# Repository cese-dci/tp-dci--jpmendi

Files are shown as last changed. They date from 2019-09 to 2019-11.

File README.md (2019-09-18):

# tp-dci--jpmendi
tp-dci--jpmendi created by GitHub Classroom

ARCHIVOS DEL TPFINAL DE DISEÑO DE PCB

El presente modulo es un control de motor de continua mediante de relay, con sensor de corriente,
para detener el mismo segun determinado torque, utilizando para ello un dip switch donde se pueden
activar distintas resistencias como referencias para que un PIC active o desactive los releay (uno para cada lado y 
un tercer relay que es para activar o desactivar la placa)

Posee dos entradas para los interruptores que estan fuera de la placa. y dos salidas a los motores

UN DETALLE: Requiere agregar ciertas pistas a la mascara antisoldante para para poder estañarlas luego de terminado el PCB

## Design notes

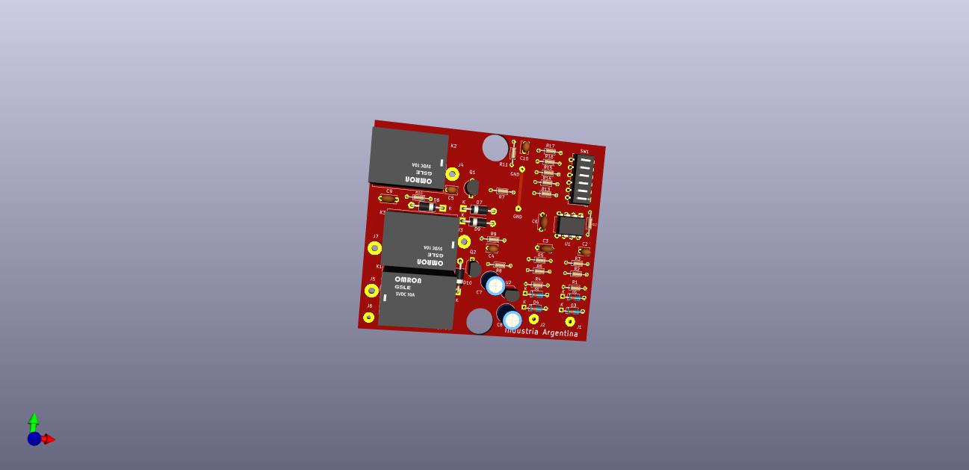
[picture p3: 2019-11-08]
TPFINAL2NOV19/DriverConSensor.jpg

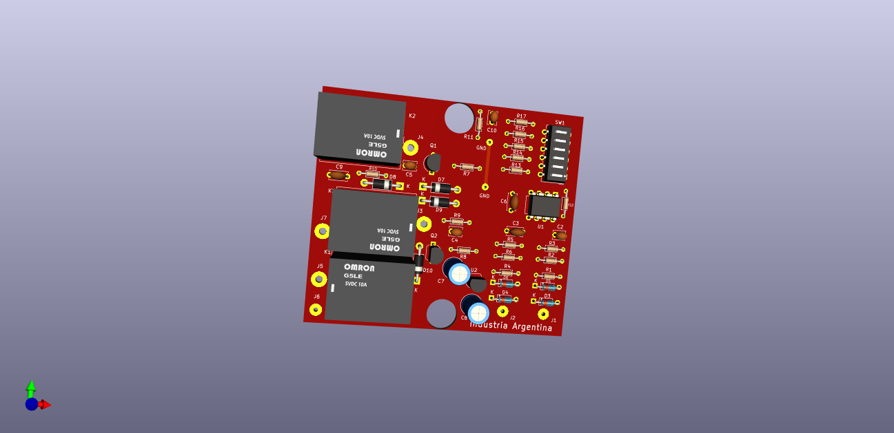
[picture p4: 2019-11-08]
TPFINAL2NOV19/DriverConSensor.png

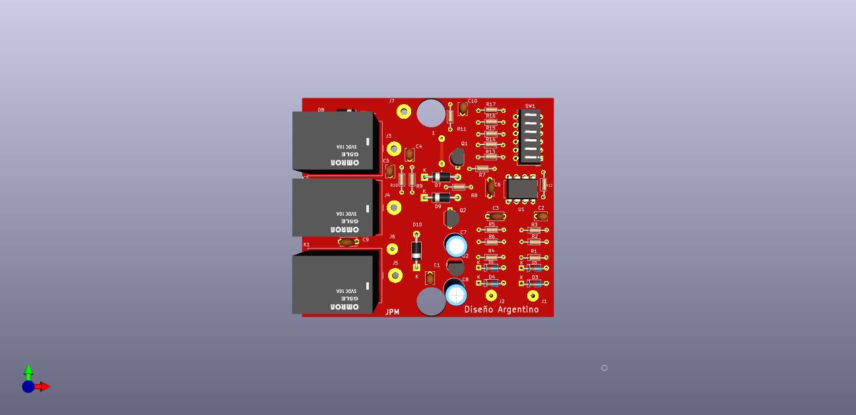
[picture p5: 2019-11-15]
TPFINAL2NOV19/Shapes3D/DriverConSensor.jpg

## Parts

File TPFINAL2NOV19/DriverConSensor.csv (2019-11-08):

Id | Designator | Package | Quantity | Designation | Supplier and ref
1 | K3,K2 | Relay_SPDT_Omron-G5LE-1 | 2 | FRS10CS10-12V
2 | K1 | Relay_SPDT_Omron-G5LE-1 | 1 | Switch de Encendido
3 | C9 | C_Disc_D5.0mm_W2.5mm_P5.00mm | 1 | 102
4 | C6,C3 | C_Disc_D5.0mm_W2.5mm_P5.00mm | 2 | 104
5 | U3 | SOIC-8_3.9x4.9mm_P1.27mm | 1 | ACS714T-30A
6 | U2 | TO-92_Inline | 1 | L78L05_TO92
7 | GND,GND | SolderWirePad_1x01_Drill0.8mm | 2 | SolderWirePad_1x01_Drill0.8mm
8 | D7,D8,D9,D10 | D_DO-41_SOD81_P10.16mm_Horizontal | 4 | 1N4004
9 | C1,C2,C4,C5 | C_Disc_D3.8mm_W2.6mm_P2.50mm | 4 | 104
10 | C7 | C_Radial_D6.3mm_H11.0mm_P2.50mm | 1 | 220uF
11 | C8 | C_Radial_D6.3mm_H11.0mm_P2.50mm | 1 | 100uF
12 | C10 | C_Disc_D3.8mm_W2.6mm_P2.50mm | 1 | 102
13 | D3,D4,D5,D6 | D_DO-35_SOD27_P7.62mm_Horizontal | 4 | 1N4148
14 | J1 | SolderWirePad_1x01_Drill1.2mm | 1 | PULS1
15 | J2 | SolderWirePad_1x01_Drill1.2mm | 1 | PULS2
16 | J3 | SolderWirePad_1x01_Drill2mm | 1 | MotorT2
17 | J4 | SolderWirePad_1x01_Drill2mm | 1 | MotorT1
18 | J5 | SolderWirePad_1x01_Drill2mm | 1 | VIn+12
19 | J6 | SolderWirePad_1x01_Drill1.2mm | 1 | Contac12V
20 | J7 | SolderWirePad_1x01_Drill2mm | 1 | GND
21 | Q1,Q2 | TO-92_Inline_Wide | 2 | BC337
22 | R1,R2,R4,R6 | R_Axial_DIN0204_L3.6mm_D1.6mm_P7.62mm_Horizontal | 4 | 100K
23 | R3,R5,R11 | R_Axial_DIN0204_L3.6mm_D1.6mm_P7.62mm_Horizontal | 3 | 10K
24 | R7,R8,R16 | R_Axial_DIN0204_L3.6mm_D1.6mm_P7.62mm_Horizontal | 3 | 5.6k
25 | R9,R10 | R_Axial_DIN0204_L3.6mm_D1.6mm_P7.62mm_Horizontal | 2 | 100
26 | R12 | R_Axial_DIN0204_L3.6mm_D1.6mm_P7.62mm_Horizontal | 1 | 10k
27 | R13 | R_Axial_DIN0204_L3.6mm_D1.6mm_P7.62mm_Horizontal | 1 | 3.3k
28 | R14 | R_Axial_DIN0204_L3.6mm_D1.6mm_P7.62mm_Horizontal | 1 | 3.9k
29 | R15 | R_Axial_DIN0204_L3.6mm_D1.6mm_P7.62mm_Horizontal | 1 | 4.7k
30 | R17 | R_Axial_DIN0204_L3.6mm_D1.6mm_P7.62mm_Horizontal | 1 | 9.2k
31 | SW1 | SW_DIP_SPSTx06_Slide_6.7x16.8mm_W7.62mm_P2.54mm_LowProfile | 1 | SW_DIP_x06
32 | U1 | DIP-8_W7.62mm | 1 | PIC12F675-IP

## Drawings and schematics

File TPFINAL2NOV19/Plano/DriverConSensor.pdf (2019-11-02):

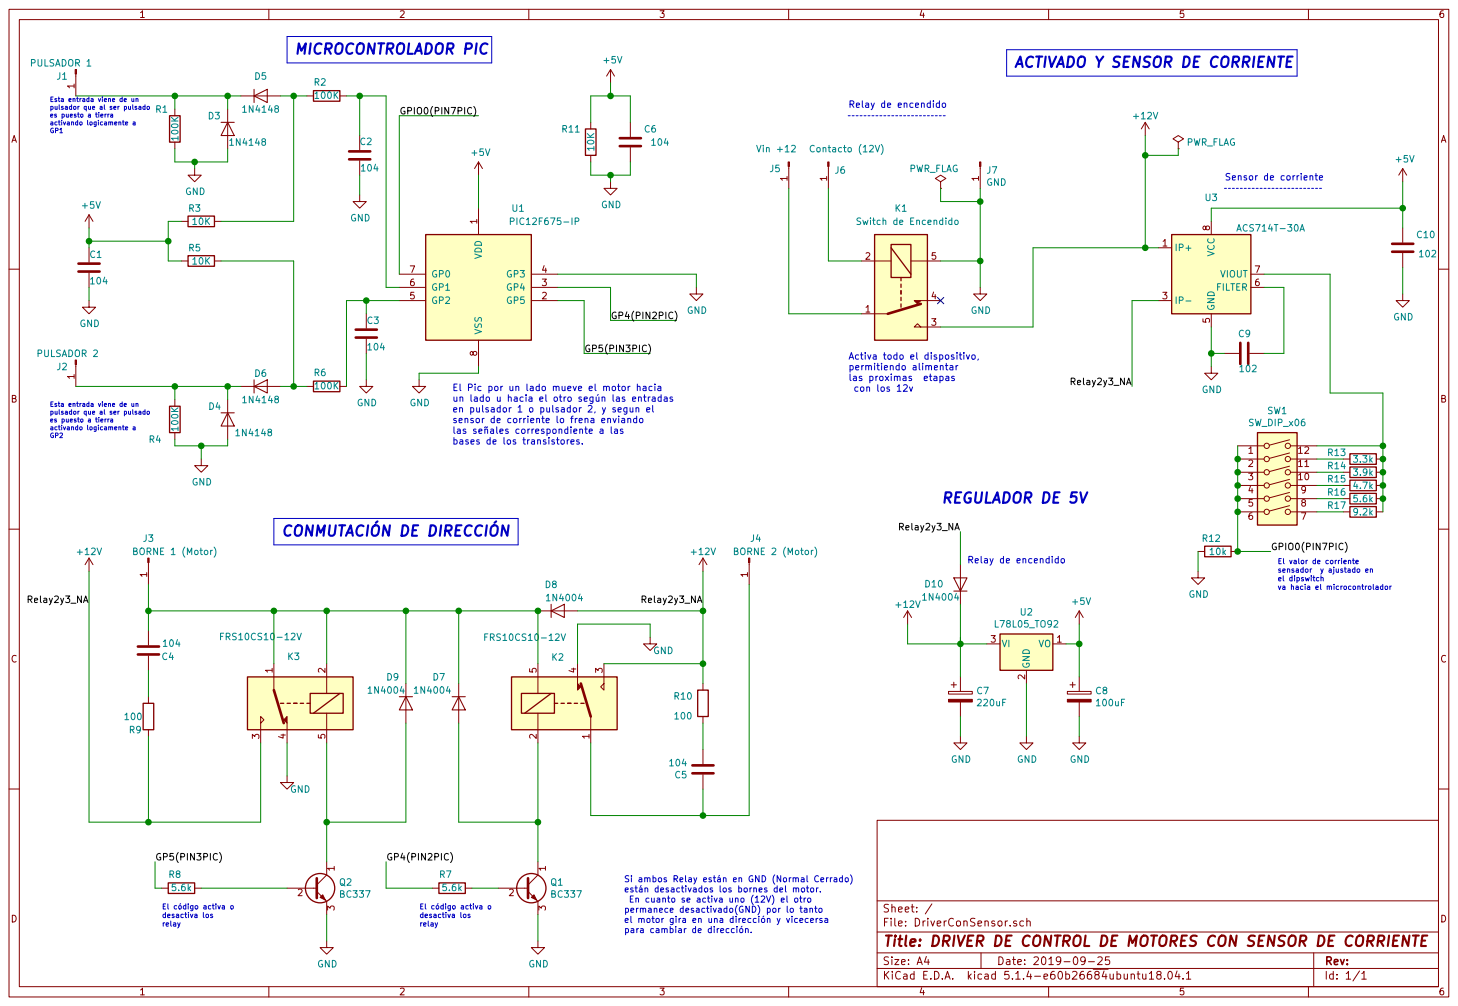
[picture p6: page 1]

ACTIVADO Y SENSOR DE CORRIENTE
9 SW1 SW_DIP_x06 PWR_FLAG

Esta entrada viene de un
pulsador que al ser pulsado
es puesto a tierra

J7GND
el dipswitch va hacia el microcontrolador Sensor de corriente Relay de encendido

File: DriverConSensor.sch Sheet: / VDD

El Pic por un lado mueve el motor hacia
un lado u hacia el otro según las entradas
en pulsador 1 o pulsador 2, y segun el sensor de corriente lo frena enviando

las señales correspondiente a las bases de los transistores. Esta entrada viene de un

El valor de corriente sensador y ajustado en

En cuanto se activa uno (12V) el otro permanece desactivado(GND) por lo tanto el motor gira en una dirección y vicecersa para cambiar de dirección.

El código activa o desactiva los relay

Id: 1/1 Title: DRIVER DE CONTROL DE MOTORES CON SENSOR DE CORRIENTE

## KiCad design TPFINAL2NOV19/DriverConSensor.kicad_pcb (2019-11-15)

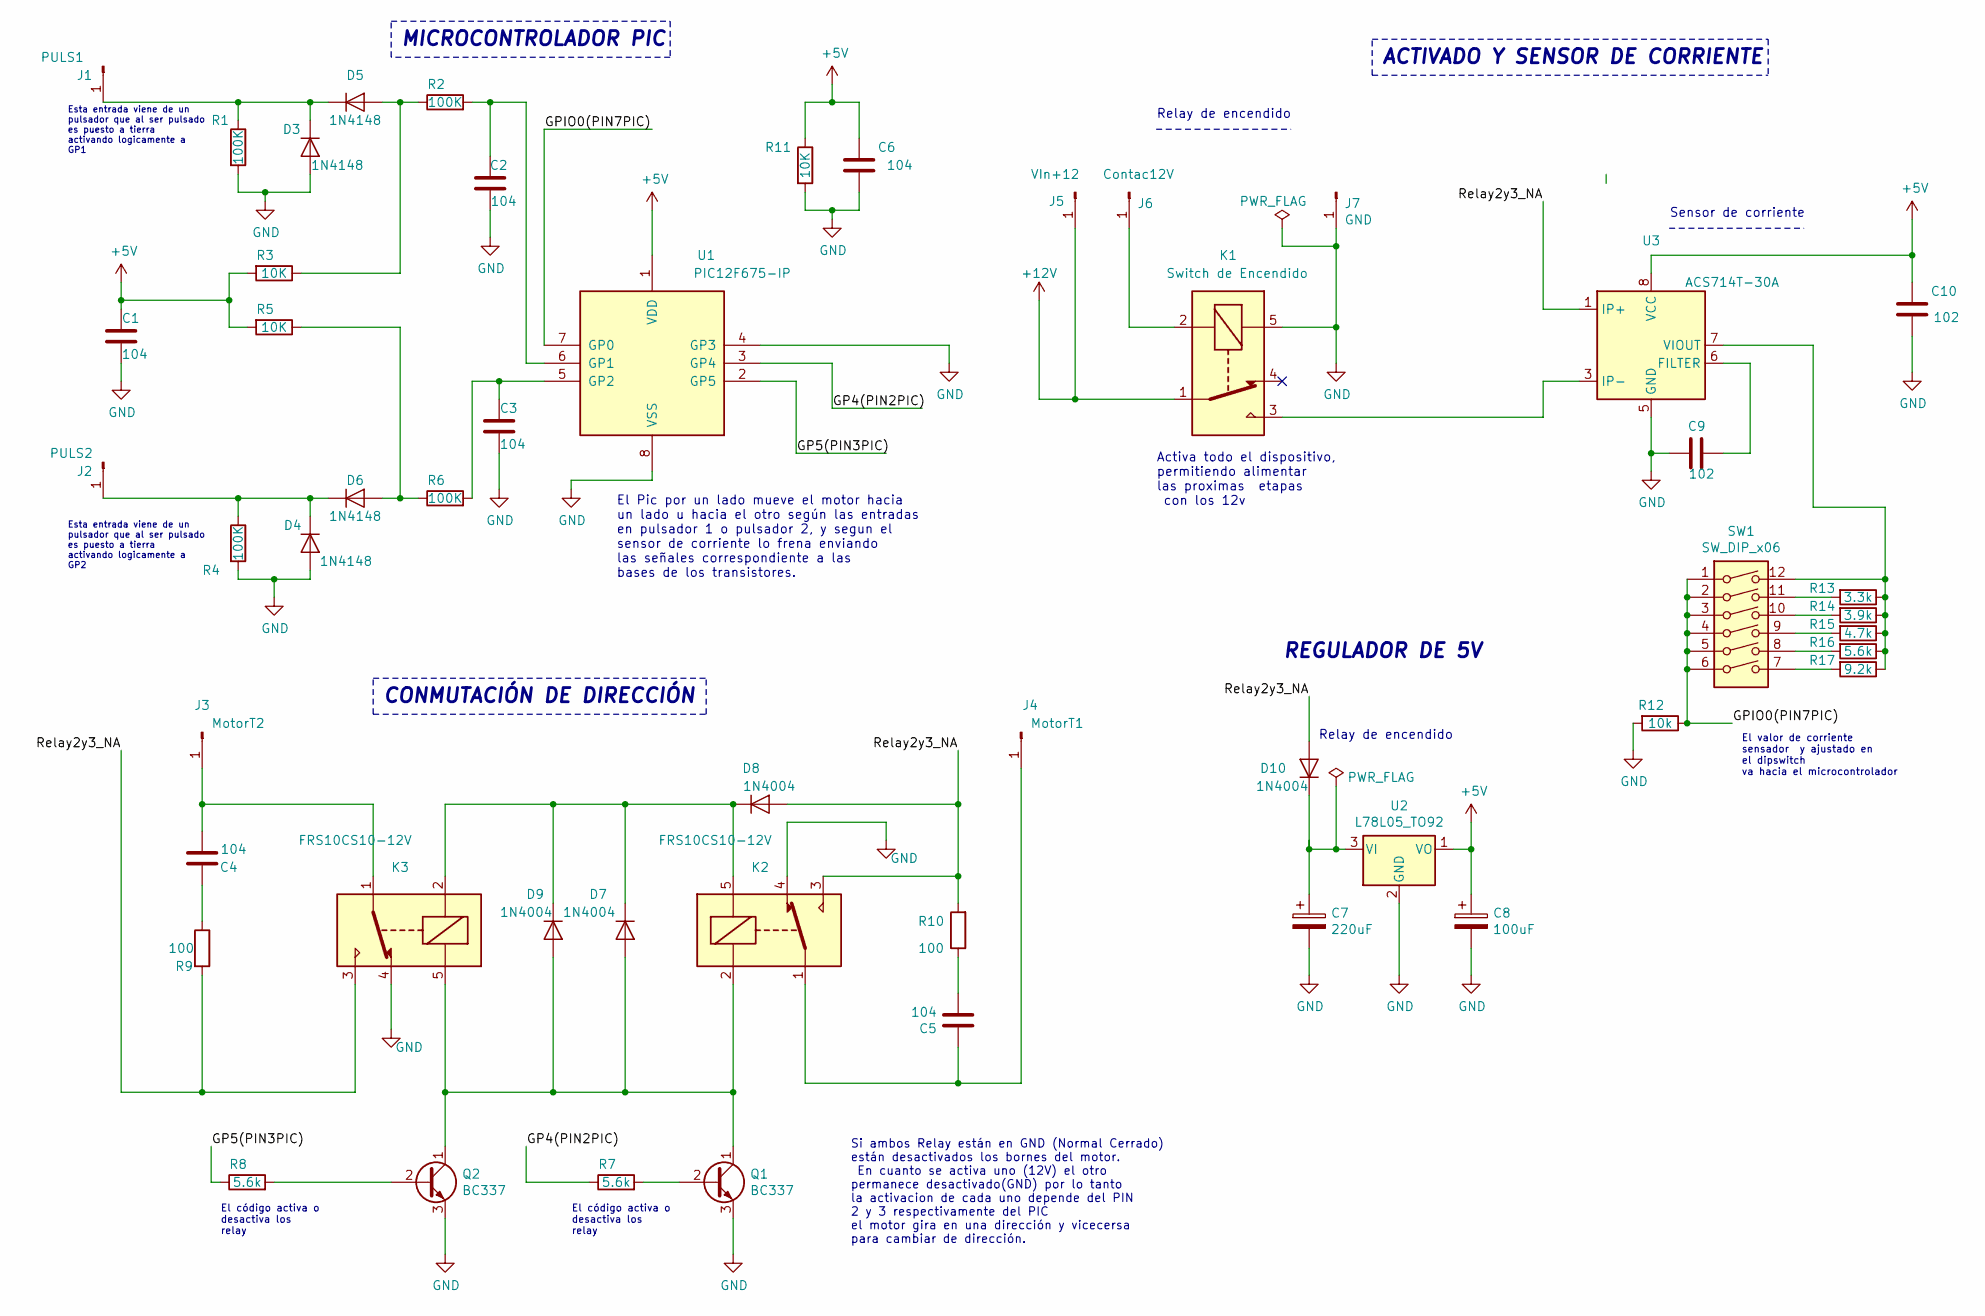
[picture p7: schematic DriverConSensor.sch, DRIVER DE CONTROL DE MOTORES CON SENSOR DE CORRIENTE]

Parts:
C1, C2, C4, C5: 104; C_Disc_D3.8mm_W2.6mm_P2.50mm
C3, C6: 104; C_Disc_D5.0mm_W2.5mm_P5.00mm
C7: 220uF; C_Radial_D6.3mm_H11.0mm_P2.50mm
C8: 100uF; C_Radial_D6.3mm_H11.0mm_P2.50mm
C9: 102; C_Disc_D5.0mm_W2.5mm_P5.00mm
C10: 102; C_Disc_D3.8mm_W2.6mm_P2.50mm
D3, D4, D5, D6: 1N4148; D_DO-35_SOD27_P7.62mm_Horizontal
D7, D8, D9, D10: 1N4004; D_DO-41_SOD81_P10.16mm_Horizontal
J1: PULS1; SolderWirePad_1x01_Drill1.2mm
J2: PULS2; SolderWirePad_1x01_Drill1.2mm
J3: MotorT2; SolderWirePad_1x01_Drill2mm
J4: MotorT1; SolderWirePad_1x01_Drill2mm
J5: VIn+12; SolderWirePad_1x01_Drill2mm
J6: Contac12V; SolderWirePad_1x01_Drill1.2mm
J7: GND; SolderWirePad_1x01_Drill2mm
K1: Switch de Encendido; Relay_SPDT_Omron-G5LE-1
K2, K3: FRS10CS10-12V; Relay_SPDT_Omron-G5LE-1
Q1, Q2: BC337; TO-92_Inline_Wide
R1, R2, R4, R6: 100K; R_Axial_DIN0204_L3.6mm_D1.6mm_P7.62mm_Horizontal
R3, R5, R11: 10K; R_Axial_DIN0204_L3.6mm_D1.6mm_P7.62mm_Horizontal
R7, R8, R16: 5.6k; R_Axial_DIN0204_L3.6mm_D1.6mm_P7.62mm_Horizontal
R9, R10: 100; R_Axial_DIN0204_L3.6mm_D1.6mm_P7.62mm_Horizontal
R12: 10k; R_Axial_DIN0204_L3.6mm_D1.6mm_P7.62mm_Horizontal
R13: 3.3k; R_Axial_DIN0204_L3.6mm_D1.6mm_P7.62mm_Horizontal
R14: 3.9k; R_Axial_DIN0204_L3.6mm_D1.6mm_P7.62mm_Horizontal
R15: 4.7k; R_Axial_DIN0204_L3.6mm_D1.6mm_P7.62mm_Horizontal
R17: 9.2k; R_Axial_DIN0204_L3.6mm_D1.6mm_P7.62mm_Horizontal
SW1: SW_DIP_x06; SW_DIP_SPSTx06_Slide_6.7x16.8mm_W7.62mm_P2.54mm_LowProfile
U1: PIC12F675-IP; DIP-8_W7.62mm
U2: L78L05_TO92; TO-92_Inline
U3: ACS714T-30A; SOIC-8_3.9x4.9mm_P1.27mm

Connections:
+5V: C1.1, C6.1, C8.1, C10.1, R3.2, R5.2, R11.1, U1.1 (VDD), U2.1 (VO), U3.8 (VCC)
+12V: J5.1, K1.1
/GP4(PIN2PIC): R7.1, U1.3 (GP4)
/GP5(PIN3PIC): R8.1, U1.2 (GP5)
/GPIO0(PIN7PIC): R12.1, SW1.1, SW1.2, SW1.3, SW1.4, SW1.5, SW1.6, U1.7 (GP0)
/Relay2y3_NA: D8.2 (A), D10.2 (A), K2.3, K3.3, R9.2, R10.2, U3.1 (IP+), U3.2 (IP+)
GND: C1.2, C2.1, C3.2, C6.2, C7.2, C8.2, C9.2, C10.2, D3.2 (A), D4.2 (A), J7.1, K1.5, K2.4, K3.4, Q1.3 (E), Q2.3 (E), R1.2, R4.2, R11.2, R12.2, U1.4 (GP3), U1.8 (VSS), U2.2 (GND), U3.5 (GND)
unnamed: C2.2, R2.2, U1.6 (GP1)
unnamed: C3.1, R6.2, U1.5 (GP2)
unnamed: C4.1, R9.1
unnamed: C4.2, J3.1, K3.1
unnamed: C5.1, J4.1, K2.1
unnamed: C5.2, R10.1
unnamed: C7.1, D10.1 (K), U2.3 (VI)
unnamed: C9.1, U3.6 (FILTER)
unnamed: D3.1 (K), D5.1 (K), J1.1, R1.1
unnamed: D4.1 (K), D6.1 (K), J2.1, R4.1
unnamed: D5.2 (A), R2.1, R3.1
unnamed: D6.2 (A), R5.1, R6.1
unnamed: D7.1 (K), D8.1 (K), D9.1 (K), K2.5, K3.2
unnamed: D7.2 (A), D9.2 (A), K2.2, K3.5, Q1.1 (C), Q2.1 (C)
unnamed: J6.1, K1.2
unnamed: K1.3, U3.3 (IP-), U3.4 (IP-)
unnamed: Q1.2 (B), R7.2
unnamed: Q2.2 (B), R8.2
unnamed 26: R13.1, R14.1, R15.1, R16.1, R17.1, SW1.12, U3.7 (VIOUT); also elsewhere on the board
unnamed: R13.2, SW1.11
unnamed: R14.2, SW1.10
unnamed: R15.2, SW1.9
unnamed: R16.2, SW1.8
unnamed: R17.2, SW1.7

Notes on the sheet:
El valor de corriente sensador y ajustado en el dipswitch va hacia el microcontrolador
Sensor de corriente
MICROCONTROLADOR PIC
Relay de encendido
Activa todo el dispositivo, permitiendo alimentar las proximas etapas con los 12v
El Pic por un lado mueve el motor hacia un lado u hacia el otro según las entradas en pulsador 1 o pulsador 2, y segun el sensor de corriente lo frena enviando las señales correspondiente a las bases de los transistores.
Esta entrada viene de un pulsador que al ser pulsado es puesto a tierra activando logicamente a GP2
Esta entrada viene de un pulsador que al ser pulsado es puesto a tierra activando logicamente a GP1
Si ambos Relay están en GND (Normal Cerrado) están desactivados los bornes del motor. En cuanto se activa uno (12V) el otro permanece desactivado(GND) por lo tanto la activacion de cada uno depende del PIN 2 y 3 respectivamente del PIC el motor gira en una dirección y vicecersa para cambiar de dire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
El código activa o desactiva los relay
CONMUTACIÓN DE DIRECCIÓN
ACTIVADO Y SENSOR DE CORRIENTE
REGULADOR DE 5V

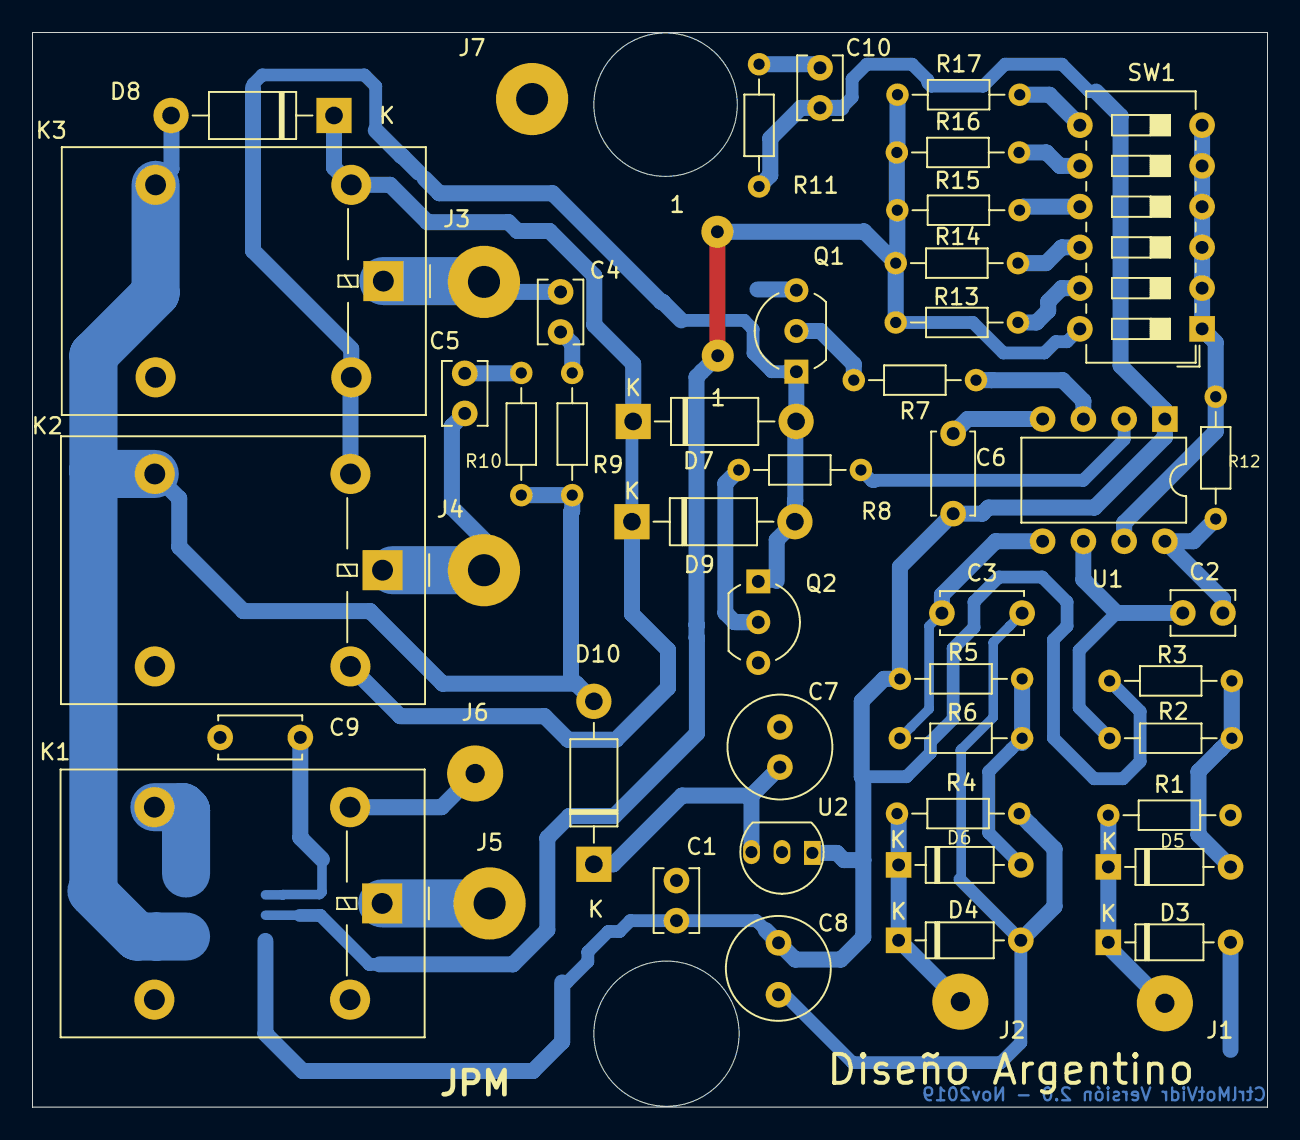
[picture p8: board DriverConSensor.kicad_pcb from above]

Board: 2 copper layers, 77.0 x 67.0 mm, 53 parts (1 on the bottom side), 31 nets.

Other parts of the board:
1, 1#2: SolderWirePad_1x01_Drill0.8mm

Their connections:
unnamed 26: 1.2, 1#2.1; also elsewhere on the board
